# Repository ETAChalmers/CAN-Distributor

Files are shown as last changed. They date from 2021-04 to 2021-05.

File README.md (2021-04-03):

CAN Distributor, to simplify connecting things to the CAN bus.

## RJ10 Pinout (4P4C)

Equivalent with RJ22.
Pinout is based on the CANOpen standard, as specified in:

https://www.phoenixcontact.com/assets/downloads_ed/global/web_dwl_technical_info/CANopen.pdf



## RJ45 Pinout (8P8C)

Pinout is based on the CANOpen standard, as specified in:

https://www.phoenixcontact.com/assets/downloads_ed/global/web_dwl_technical_info/CANopen.pdf



## Board Concept

Each distribution card delivers CAN and optionally power to its Nodes. Power is only distributed over the
Node ports. This is to avoid any complex problems regarding PSU load sharing, ground loops, etc...
Power is indicated by PWR_LED. Voltage and allowable current draw depends on the connected PSU.

It is not reasonable to draw more than 200/300 mA over the RJ10 cables.

The board has a footprint for a termination resistor, which may be populated. **The resistor should only be
populated if the board is at one of the two edges of the CAN network.**

The Main ports and Node ports use different connectors to avoid plugging them wrong. The RJ10 ports may 
either be populated with TE Connectivity's vertical [5520257-2](https://www.te.com/usa-en/product-5520257-2.html) connectors or horizontal [1-1705949-1](https://www.te.com/usa-en/product-1-1705949-1.html) connectors.



## Mechanical

All mounting holes are for M3.

The board can be mounted to a DIN rail using Phoenix Contact's [1201578](https://www.phoenixcontact.com/online/portal/se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) or [1200993](https://www.phoenixcontact.com/online/portal/se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) rail adapters.
In that case the board is screwed to the adapters using self tapping M3 plastic screws.



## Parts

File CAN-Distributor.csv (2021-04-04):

Reference | Quantity | Value | Footprint | Datasheet | Farnell | MPN | Manufacturer | Description
D1 | 1 | D_Schottky | Diode_SMD:D_SOD-123F | https://datasheet.octopart.com/S310FA-ON-Semiconductor-datasheet-137362515.pdf | 2822559 | S310FA | ON Semiconductor
D2 | 1 | PWR_LED | Diode_SMD:D_0603_1608Metric | https://datasheet.octopart.com/SML-D12P8WT86-Rohm-datasheet-142144708.pdf | 2687486 | SML-D12P8WT86 | ROHM
D3 | 1 | TVS | Package_TO_SOT_SMD:SOT-23 | http://www.farnell.com/datasheets/2028697.pdf | 2101833 | NUP2105LT1G | ON Semiconductor
F1 | 1 | 2.5A | Fuse:Fuseholder_Cylinder-5x20mm_Schurter_0031_8201_Horizontal_Open | http://www.farnell.com/datasheets/2343287.pdf | 1162740 | 0031.8201 | SCHURTER | 5x20 mm
GD1 | 1 | GDT | CAN-Distributor:Bourns_Inc.-2036-07-SM-RPLF-MFG | https://datasheet.octopart.com/2038-15-SM-RPLF-Bourns-datasheet-15373353.pdf | 1846857 | 2036-07-SM | Bourns
J1 | 1 | 3p Terminal Block | TerminalBlock:TerminalBlock_bornier-3_P5.08mm | ~ | ~ | ~ | ~
J13 J14 J15 | 3 | 4p Terminal Block | TerminalBlock_TE-Connectivity:TerminalBlock_TE_282834-4_1x04_P2.54mm_Horizontal | ~ | ~ | ~ | ~
J2 J3 | 2 | RJ45_Shielded | CAN-Distributor:RJHSE5480 | https://www.farnell.com/cad/2360424.pdf | 3367703 | RJHSE5480 | AMPHENOL ICC
J4 J5 J6 J7 J8 J9 J10 J11 J12 J16 | 10 | RJ10 | CAN-Distributor:TE_5520257-2 | https://www.te.com/commerce/DocumentDelivery/DDEController?Action=showdoc | 1284339 | 5520257-2 | TE Connectivity
R1 | 1 | 120 | Resistor_THT:R_Axial_DIN0411_L9.9mm_D3.6mm_P15.24mm_Horizontal | ~ | ~ | ~ | ~
U1 | 1 | CL25N8-G | Package_TO_SOT_SMD:SOT-89-3 | http://www.farnell.com/datasheets/1849619.pdf | 2448489 | CL25N8-G | Microchip

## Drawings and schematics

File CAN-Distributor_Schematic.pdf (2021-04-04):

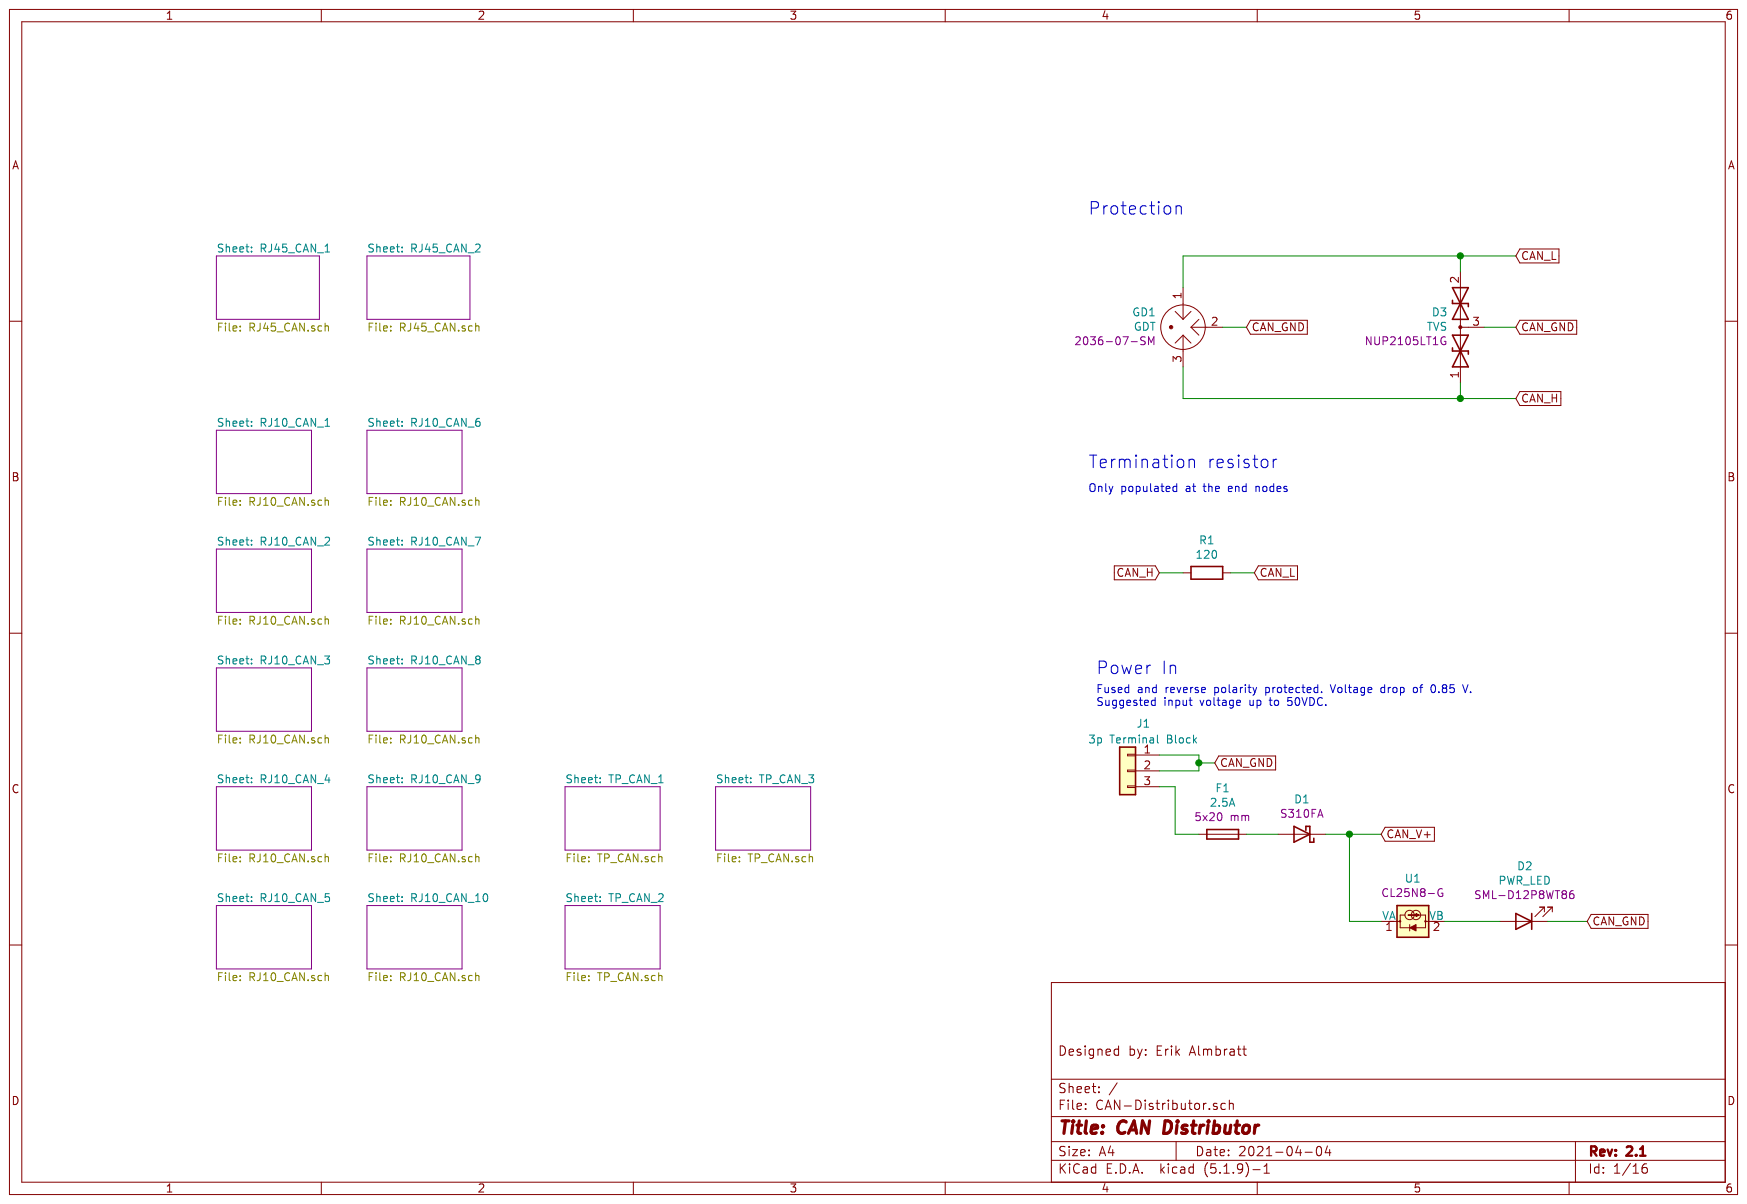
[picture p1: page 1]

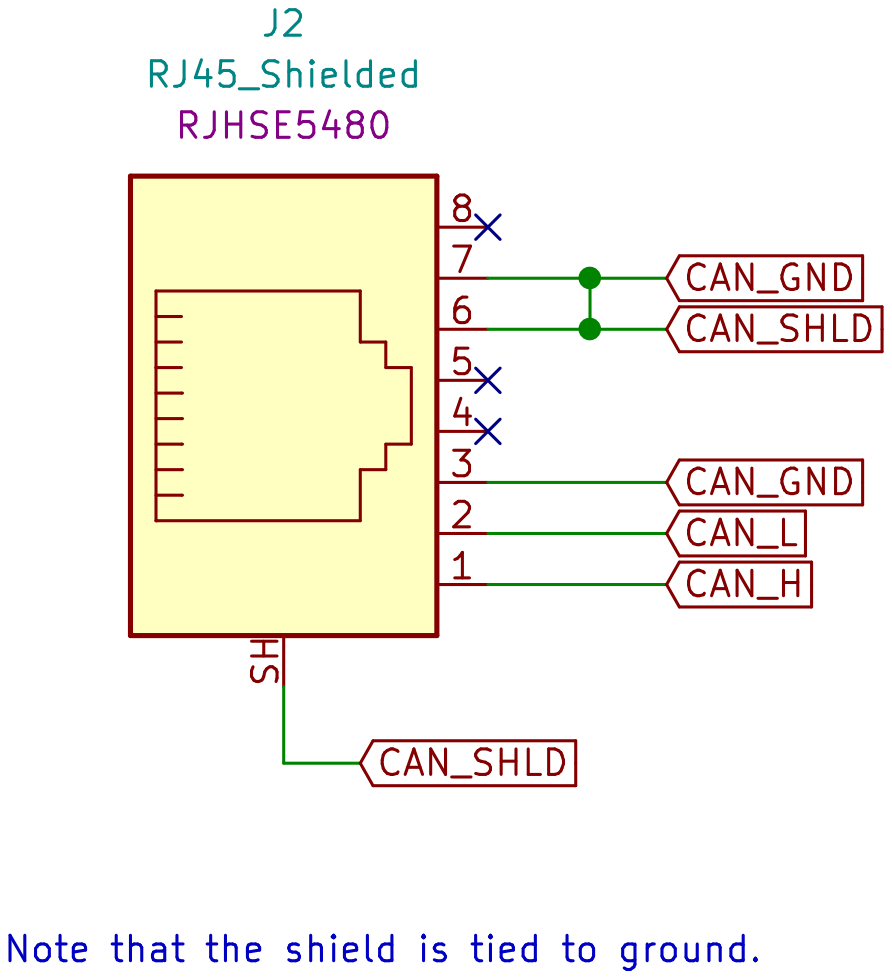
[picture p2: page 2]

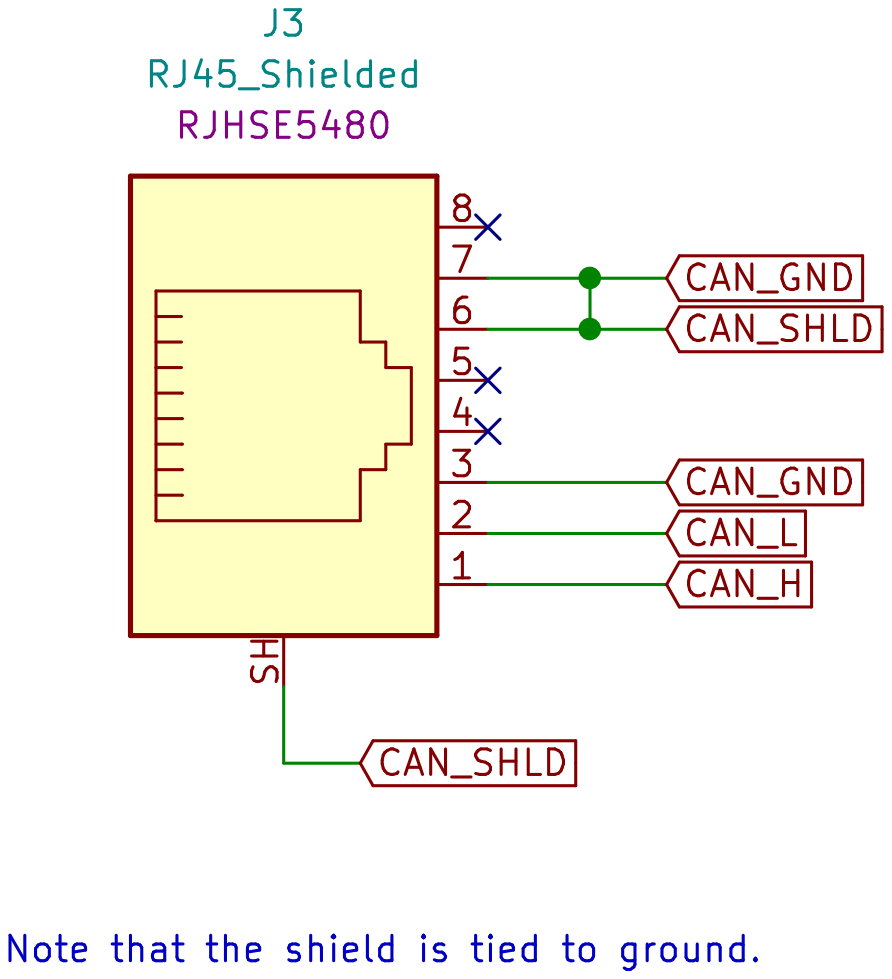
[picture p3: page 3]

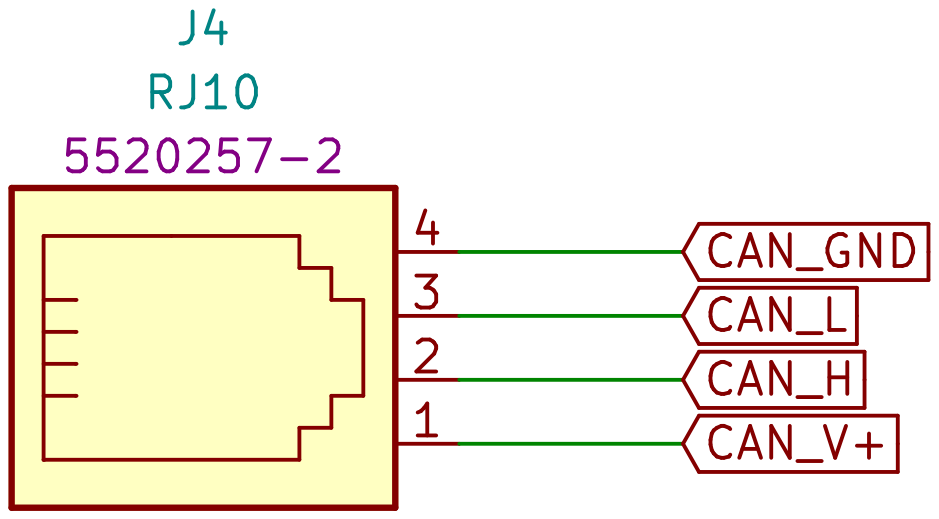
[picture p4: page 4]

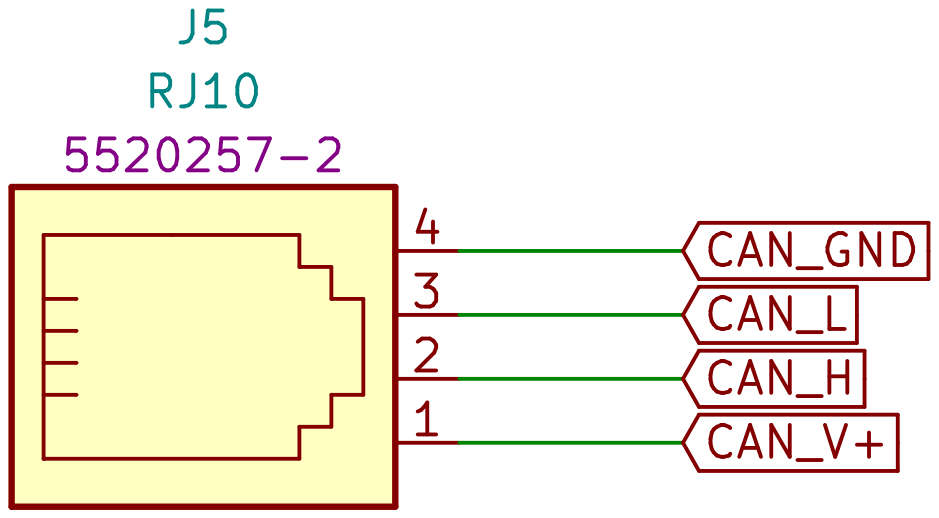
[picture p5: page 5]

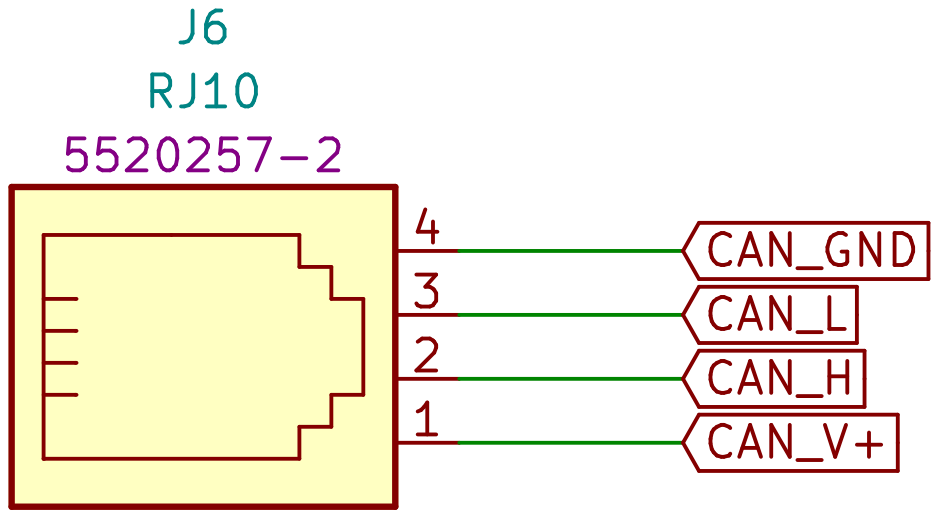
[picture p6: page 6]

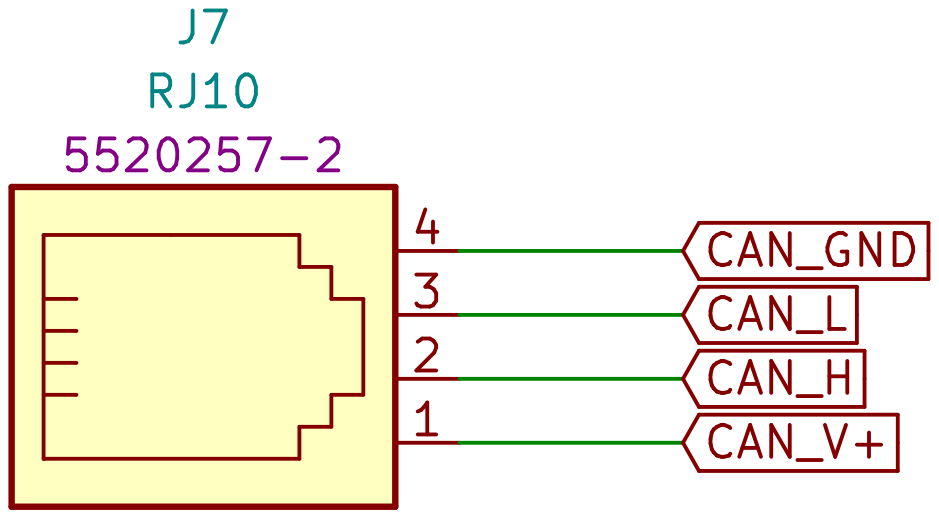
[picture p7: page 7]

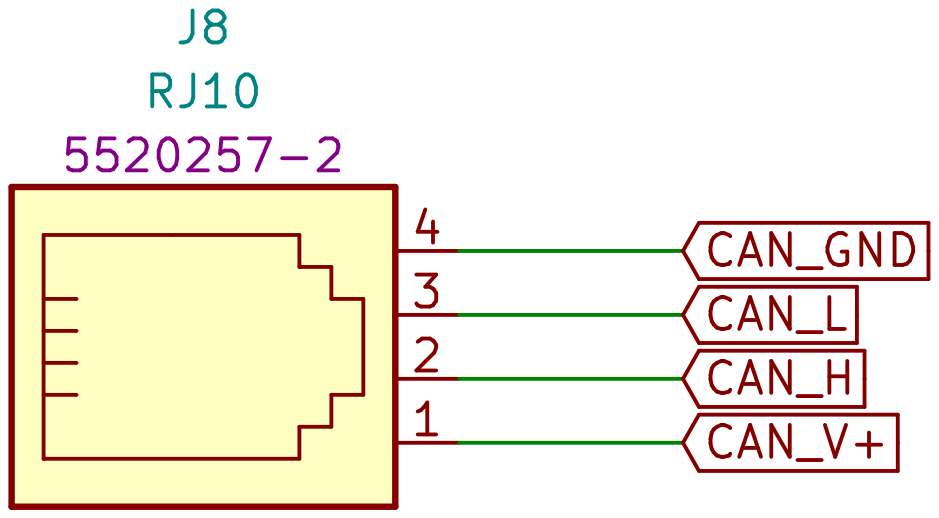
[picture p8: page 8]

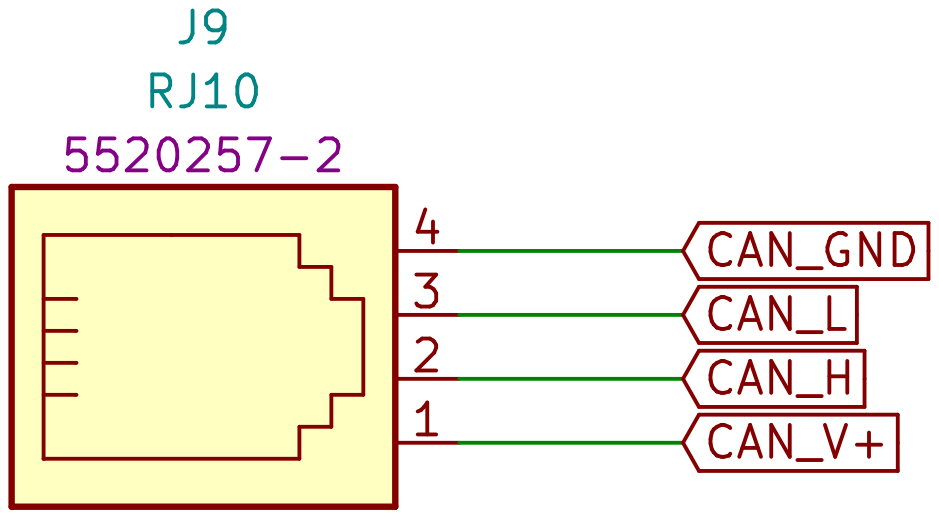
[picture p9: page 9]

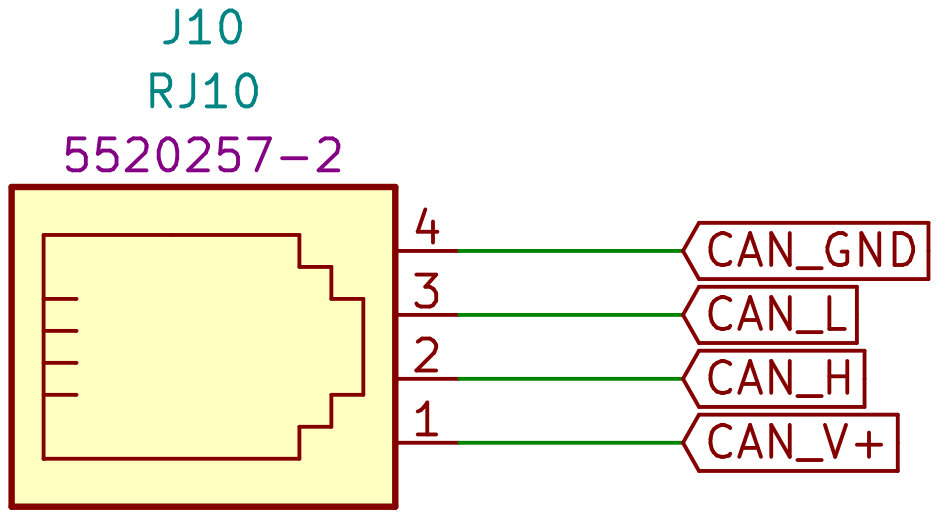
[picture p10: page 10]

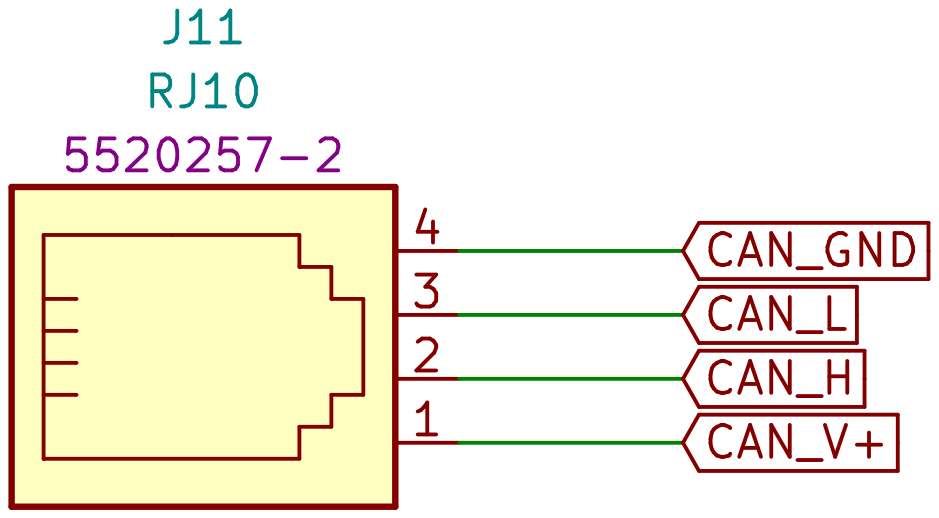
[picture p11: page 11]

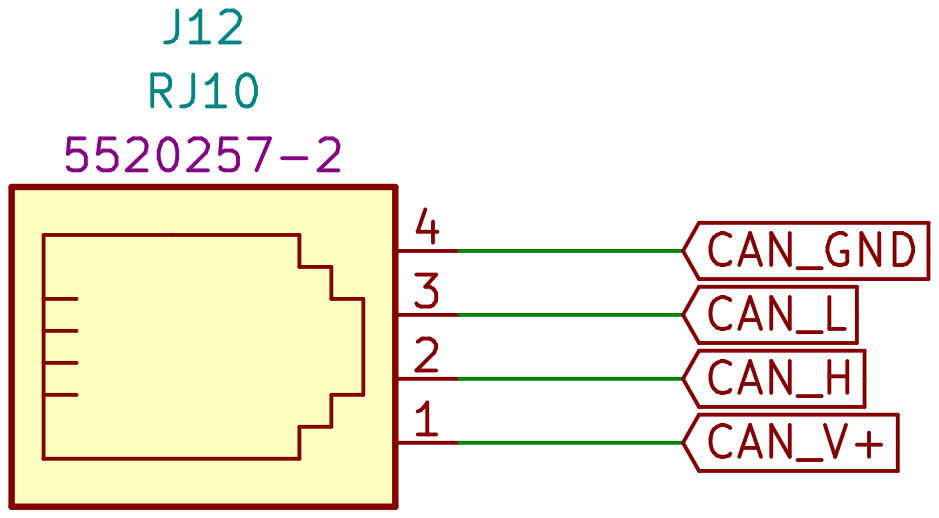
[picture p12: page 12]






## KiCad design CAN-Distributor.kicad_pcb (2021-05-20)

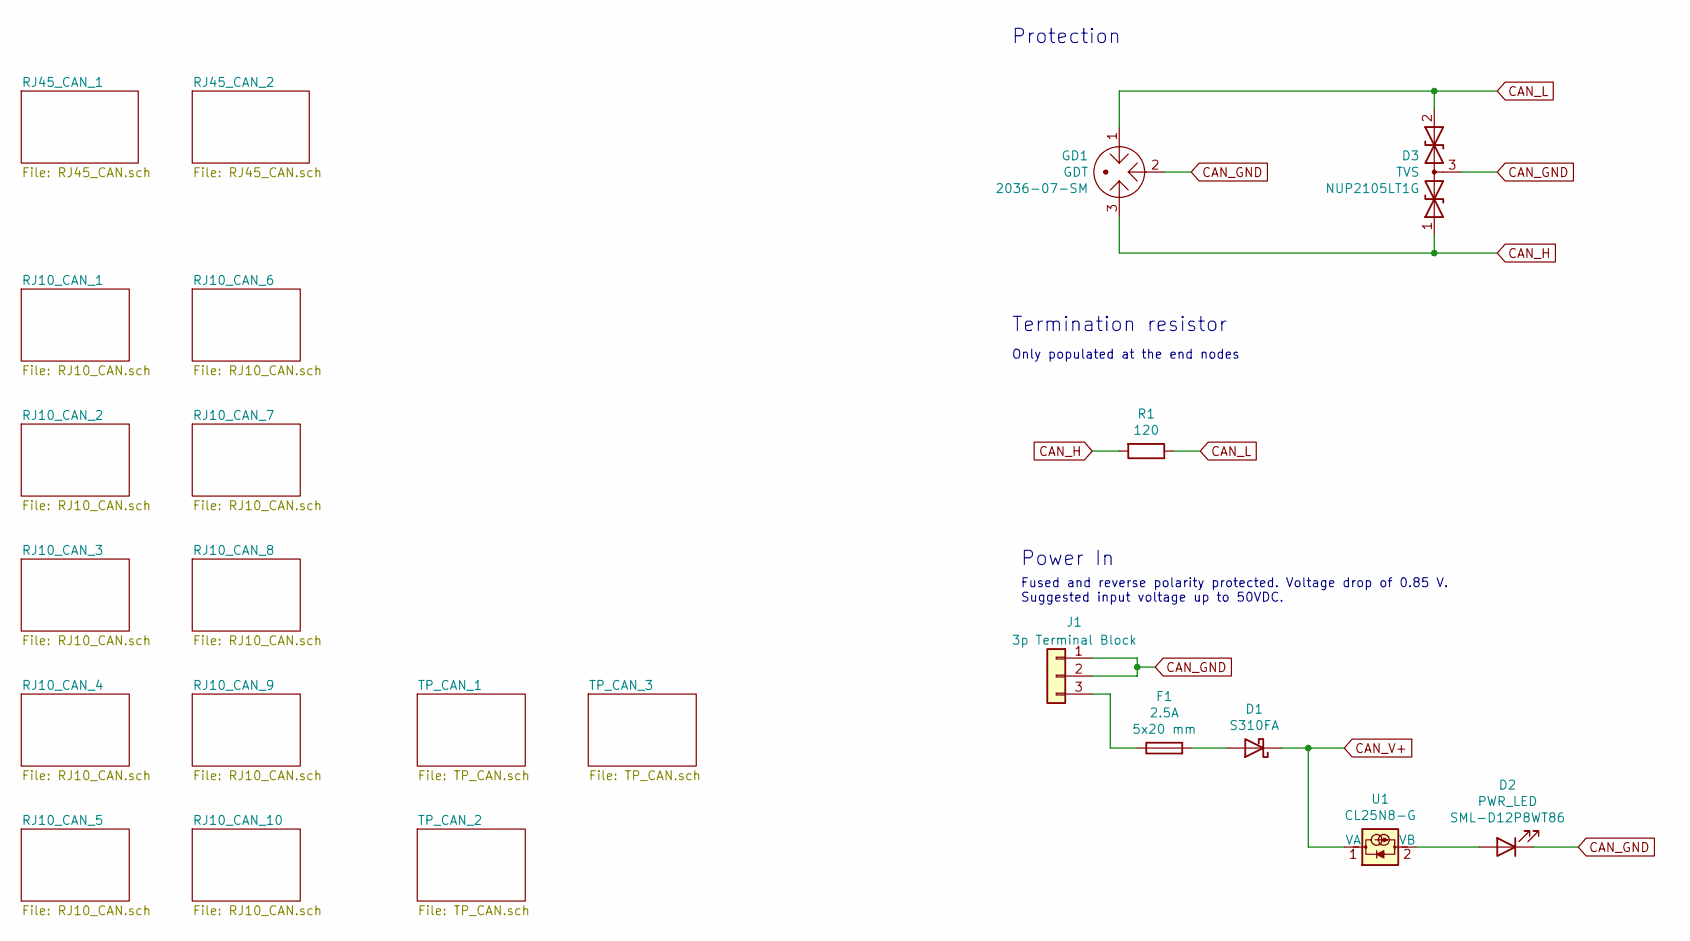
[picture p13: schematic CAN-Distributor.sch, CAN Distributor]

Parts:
D1: D_Schottky; D_SOD-123F; MPN S310FA; Farnell 2822559
D2: PWR_LED; D_0603_1608Metric; MPN SML-D12P8WT86; Farnell 2687486
D3: TVS; SOT-23; MPN NUP2105LT1G; Farnell 2101833
F1: 2.5A; Fuseholder_Cylinder-5x20mm_Schurter_0031_8201_Horizontal_Op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; MPN 0031.8201; Farnell 1162740
GD1: GDT; Bourns_Inc.-2036-07-SM-RPLF-MFG; MPN 2036-07-SM; Farnell 1846857
J1: 3p Terminal Block; TerminalBlock_bornier-3_P5.08mm
R1: 120; R_Axial_DIN0411_L9.9mm_D3.6mm_P15.24mm_Horizontal
U1: CL25N8-G; SOT-89-3; MPN CL25N8-G; Farnell 2448489

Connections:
CAN_GND: D2.1 (K), D3.3 (common), GD1.2, J1.1, J1.2; also elsewhere on the board
CAN_H: D3.1 (A1), GD1.3, R1.2; also elsewhere on the board
CAN_L: D3.2 (A2), GD1.1, R1.1; also elsewhere on the board
CAN_V+: D1.1 (K), U1.1 (VA); also elsewhere on the board
unnamed: D1.2 (A), F1.2
unnamed: D2.2 (A), U1.2 (VB)
unnamed: F1.1, J1.3

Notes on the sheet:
Only populated at the end nodes
Power In
Termination resistor
Fused and reverse polarity protected. Voltage drop of 0.85 V. Suggested input voltage up to 50VDC.
Protection

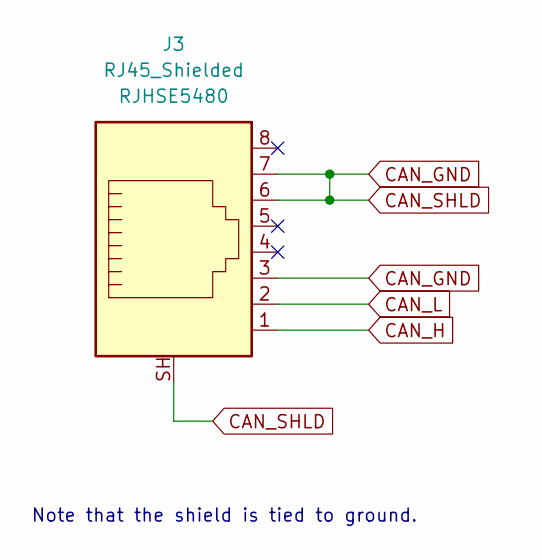
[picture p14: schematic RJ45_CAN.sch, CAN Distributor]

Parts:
J2: RJ45_Shielded; RJHSE5480; MPN RJHSE5480; Farnell 3367703

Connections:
CAN_GND: J2.3, J2.6, J2.7, J2.SH; also elsewhere on the board
CAN_H: J2.1; also elsewhere on the board
CAN_L: J2.2; also elsewhere on the board

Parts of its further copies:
J3: RJ45_Shielded; RJHSE5480; MPN RJHSE5480; Farnell 3367703

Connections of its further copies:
CAN_GND: J3.3, J3.6, J3.7, J3.SH; also elsewhere on the board
CAN_H: J3.1; also elsewhere on the board
CAN_L: J3.2; also elsewhere on the board

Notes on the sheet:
Note that the shield is tied to ground.

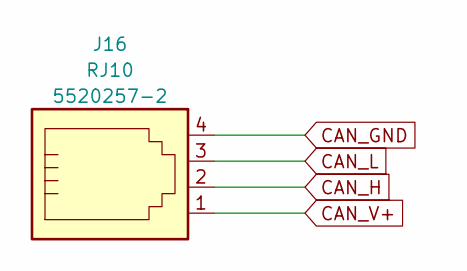
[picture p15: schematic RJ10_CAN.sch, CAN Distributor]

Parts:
J4: RJ10; TE_5520257-2; MPN 5520257-2; Farnell 1284339

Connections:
CAN_GND: J4.4; also elsewhere on the board
CAN_H: J4.2; also elsewhere on the board
CAN_L: J4.3; also elsewhere on the board
CAN_V+: J4.1; also elsewhere on the board

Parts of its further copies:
J5, J6, J7, J8, J9, J10, J11, J12, J16: RJ10; TE_5520257-2; MPN 5520257-2; Farnell 1284339

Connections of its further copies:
CAN_GND: J5.4, J6.4, J7.4, J8.4, J9.4, J10.4, J11.4, J12.4, J16.4; also elsewhere on the board
CAN_H: J5.2, J6.2, J7.2, J8.2, J9.2, J10.2, J11.2, J12.2, J16.2; also elsewhere on the board
CAN_L: J5.3, J6.3, J7.3, J8.3, J9.3, J10.3, J11.3, J12.3, J16.3; also elsewhere on the board
CAN_V+: J5.1, J6.1, J7.1, J8.1, J9.1, J10.1, J11.1, J12.1, J16.1; also elsewhere on the board

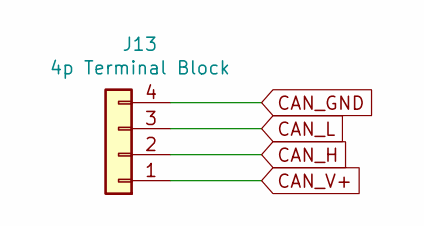
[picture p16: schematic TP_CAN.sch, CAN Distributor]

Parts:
J13: 4p Terminal Block; TerminalBlock_TE_282834-4_1x04_P2.54mm_Horizontal

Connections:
CAN_GND: J13.4; also elsewhere on the board
CAN_H: J13.2; also elsewhere on the board
CAN_L: J13.3; also elsewhere on the board
CAN_V+: J13.1; also elsewhere on the board

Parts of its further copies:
J14, J15: 4p Terminal Block; TerminalBlock_TE_282834-4_1x04_P2.54mm_Horizontal

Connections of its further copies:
CAN_GND: J14.4, J15.4; also elsewhere on the board
CAN_H: J14.2, J15.2; also elsewhere on the board
CAN_L: J14.3, J15.3; also elsewhere on the board
CAN_V+: J14.1, J15.1; also elsewhere on the board

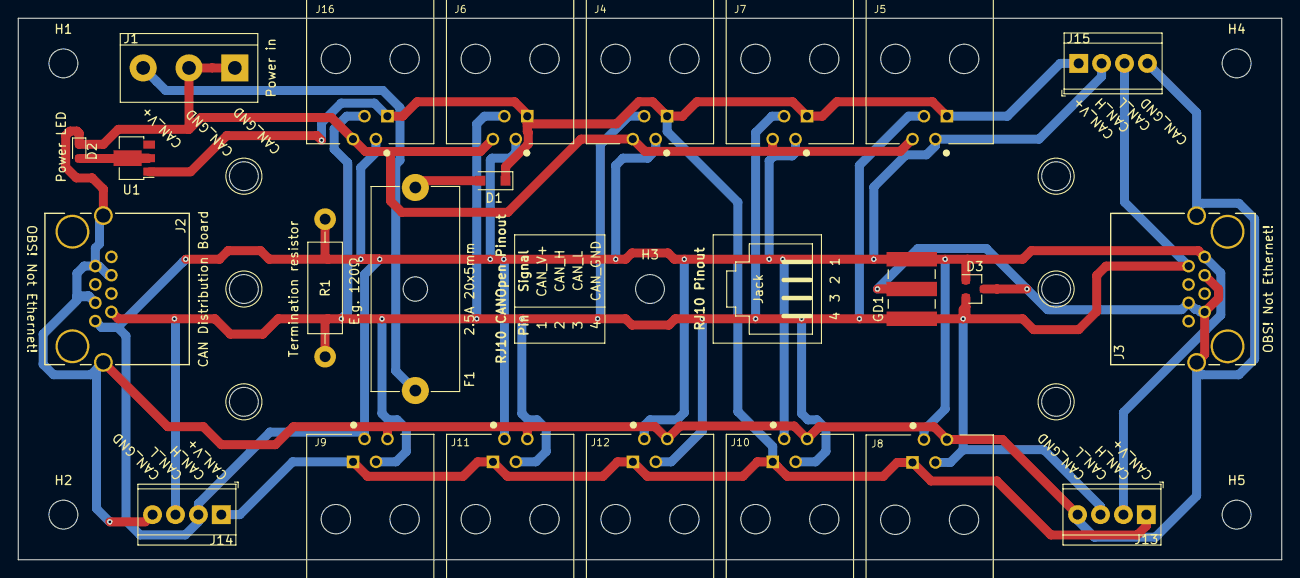
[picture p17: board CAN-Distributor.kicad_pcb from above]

Board: 2 copper layers, 140.0 x 60.0 mm, 32 parts (0 on the bottom side), 7 nets.

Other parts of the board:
G1: RJ10_CAN_Open_Pinout_Table_Silkscreen
G2: RJ10_Pinout_Silkscreen
H1, H2, H3, H4, H5: MountingHole_3.2mm_M3_DIN965
M1, M2: DINRailAdapter_3xM3_PhoenixContact_1201578

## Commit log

2021-02-26 Create project. General design done.
    [RJ45-CAN-Distributor.kicad_pcb, RJ45-CAN-Distributor.sch, RJ45_CAN.sch]
2021-02-26 Route, associate and generate bom and drawings.
    [RJ45-CAN-Distributor.csv, RJ45-CAN-Distributor.kicad_pcb, RJ45-CAN-Distributor.sch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]
2021-04-02 Add RJ40 silksreens footprints and rename old RJ45 footprints.
2021-04-03 Remove RJ45 from project title.
    [CAN-Distributor.csv, CAN-Distributor.kicad_pcb, CAN-Distributor.sch]
2021-04-03 Design v2 circuit and make footprints.
    [CAN-Distributor.sch, RJ10_CAN.sch, RJ45_CAN.sch]
2021-04-03 Perform layout. Add CAN testpoints.
    [CAN-Distributor.kicad_pcb, CAN-Distributor.sch, RJ10_CAN.sch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]
2021-04-03 Autoroute board.
    [CAN-Distributor.kicad_pcb]
2021-04-03 Export documentation.
    [CAN-Distributor.kicad_pcb]
2021-04-03 Add a tenth RJ10 connector.
    [CAN-Distributor.kicad_pcb, CAN-Distributor.sch, RJ10_CAN.sch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]
2021-04-03 Export documentation
    [CAN-Distributor.csv]
2021-04-04 Add protection TVS and GDT. Rename TP file.
    [CAN-Distributor.kicad_pcb, CAN-Distributor.sch, RJ10_CAN.sch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]
2021-04-04 Update BOM with TVS and GDT.
    [CAN-Distributor.csv]
2021-04-04 Add additional GND input
    [CAN-Distributor.csv, CAN-Distributor.kicad_pcb, CAN-Distributor.sch]
2021-05-20 Rotate RJ45 connectors and re-route.
    [CAN-Distributor.kicad_pcb]
